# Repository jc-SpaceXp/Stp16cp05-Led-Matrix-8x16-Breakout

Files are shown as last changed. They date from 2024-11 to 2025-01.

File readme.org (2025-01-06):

* STP16CP05 LED Matrix 8x16 Breakout (0805 Metric)
Note: All components have the correct name/part-number however the description and datasheet will be incorrect (if names were changed)
** Schematic
[[file:stp16cp05_led_matrix_8x16_breakout/schematic_v04.pdf]]
** BOM
[[file:stp16cp05_led_matrix_8x16_breakout/stp16cp05_led_matrix_8x16_breakout_m0805_bom.csv]]
** 3D PCB Models
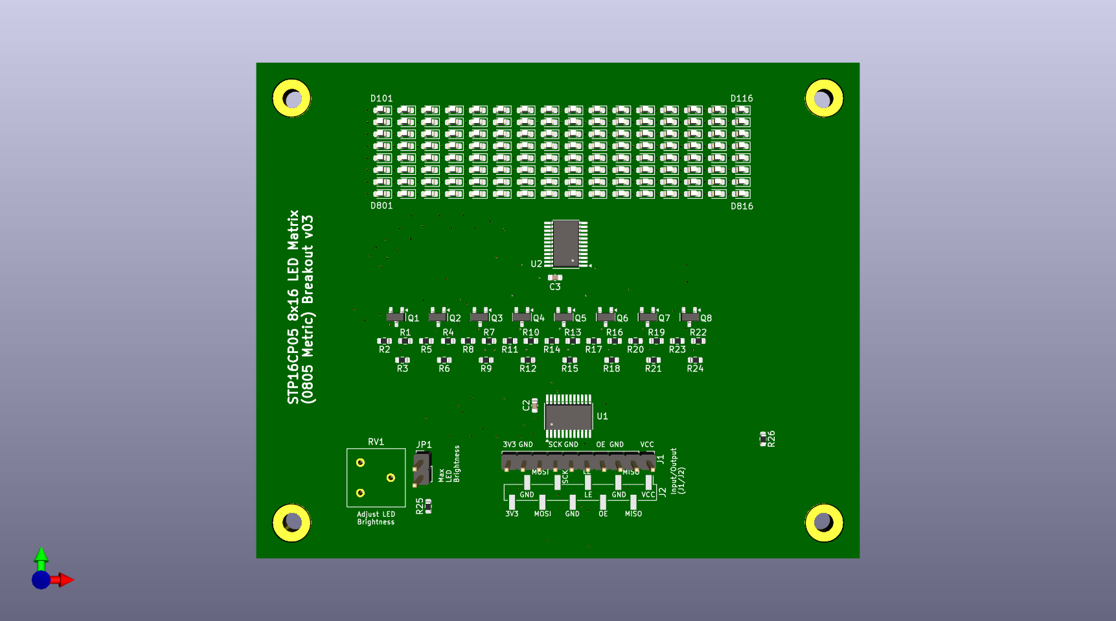
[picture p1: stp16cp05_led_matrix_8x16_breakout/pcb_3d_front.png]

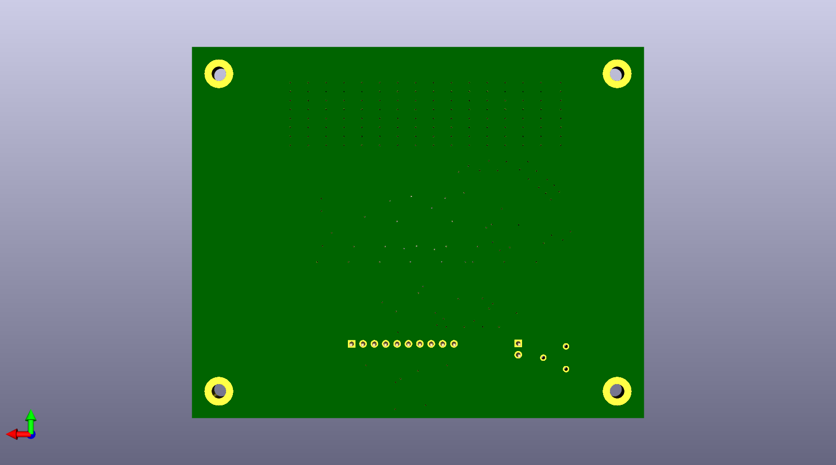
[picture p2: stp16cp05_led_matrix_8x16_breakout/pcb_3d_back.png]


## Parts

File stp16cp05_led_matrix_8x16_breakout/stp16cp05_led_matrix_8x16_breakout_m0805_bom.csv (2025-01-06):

Manufacturer Part No | Reference | Value | Qty | Footprint
C0603C104J3RACTU | C2,C3 | 100n | 2 | Capacitor_SMD:C_0603_1608Metric
LTST-C171KRKT | D101-D116,D201-D216,D301-D316,D401-D416,D501-D516,D601-D616,D701-D716,D801-D816 | LTST-C171KRKT | 128 | LED_SMD:LED_0603_1608Metric_Pad1.05x0.95mm_HandSolder
77311-101-10LF | J1 | (Input/Output) LED Matrix 2.54mm Female | 1 | Connector_PinHeader_2.54mm:PinHeader_1x10_P2.54mm_Vertical
AKSCT/G BLACK | JP1 | Short RV1 (Open) | 1 | Connector_PinHeader_2.54mm:PinHeader_1x02_P2.54mm_Vertical
DMP3125L-7 | Q1,Q2,Q3,Q4,Q5,Q6,Q7,Q8 | DMP3125L-7 | 8 | Package_TO_SOT_SMD:SOT-23
RT0603FRE075K1L | R1,R4,R7,R10,R13,R16,R19,R22 | 5K1 | 8 | Resistor_SMD:R_0603_1608Metric
RT0603DRE071KL | R2,R5,R8,R11,R14,R17,R20,R23,R25,R26 | 1K | 10 | Resistor_SMD:R_0603_1608Metric
RT0603FRE0710RL | R3,R6,R9,R12,R15,R18,R21,R24 | 10R | 8 | Resistor_SMD:R_0603_1608Metric
3386F-1-222LF | RV1 | 2K2 | 1 | Potentiometer_THT:Potentiometer_Bourns_3386F_Vertical
STP16CP05XTTR | U1,U2 | STP16CP05XT | 2 | Package_SO:HTSSOP-24-1EP_4.4x7.8mm_P0.65mm_EP3.2x5mm

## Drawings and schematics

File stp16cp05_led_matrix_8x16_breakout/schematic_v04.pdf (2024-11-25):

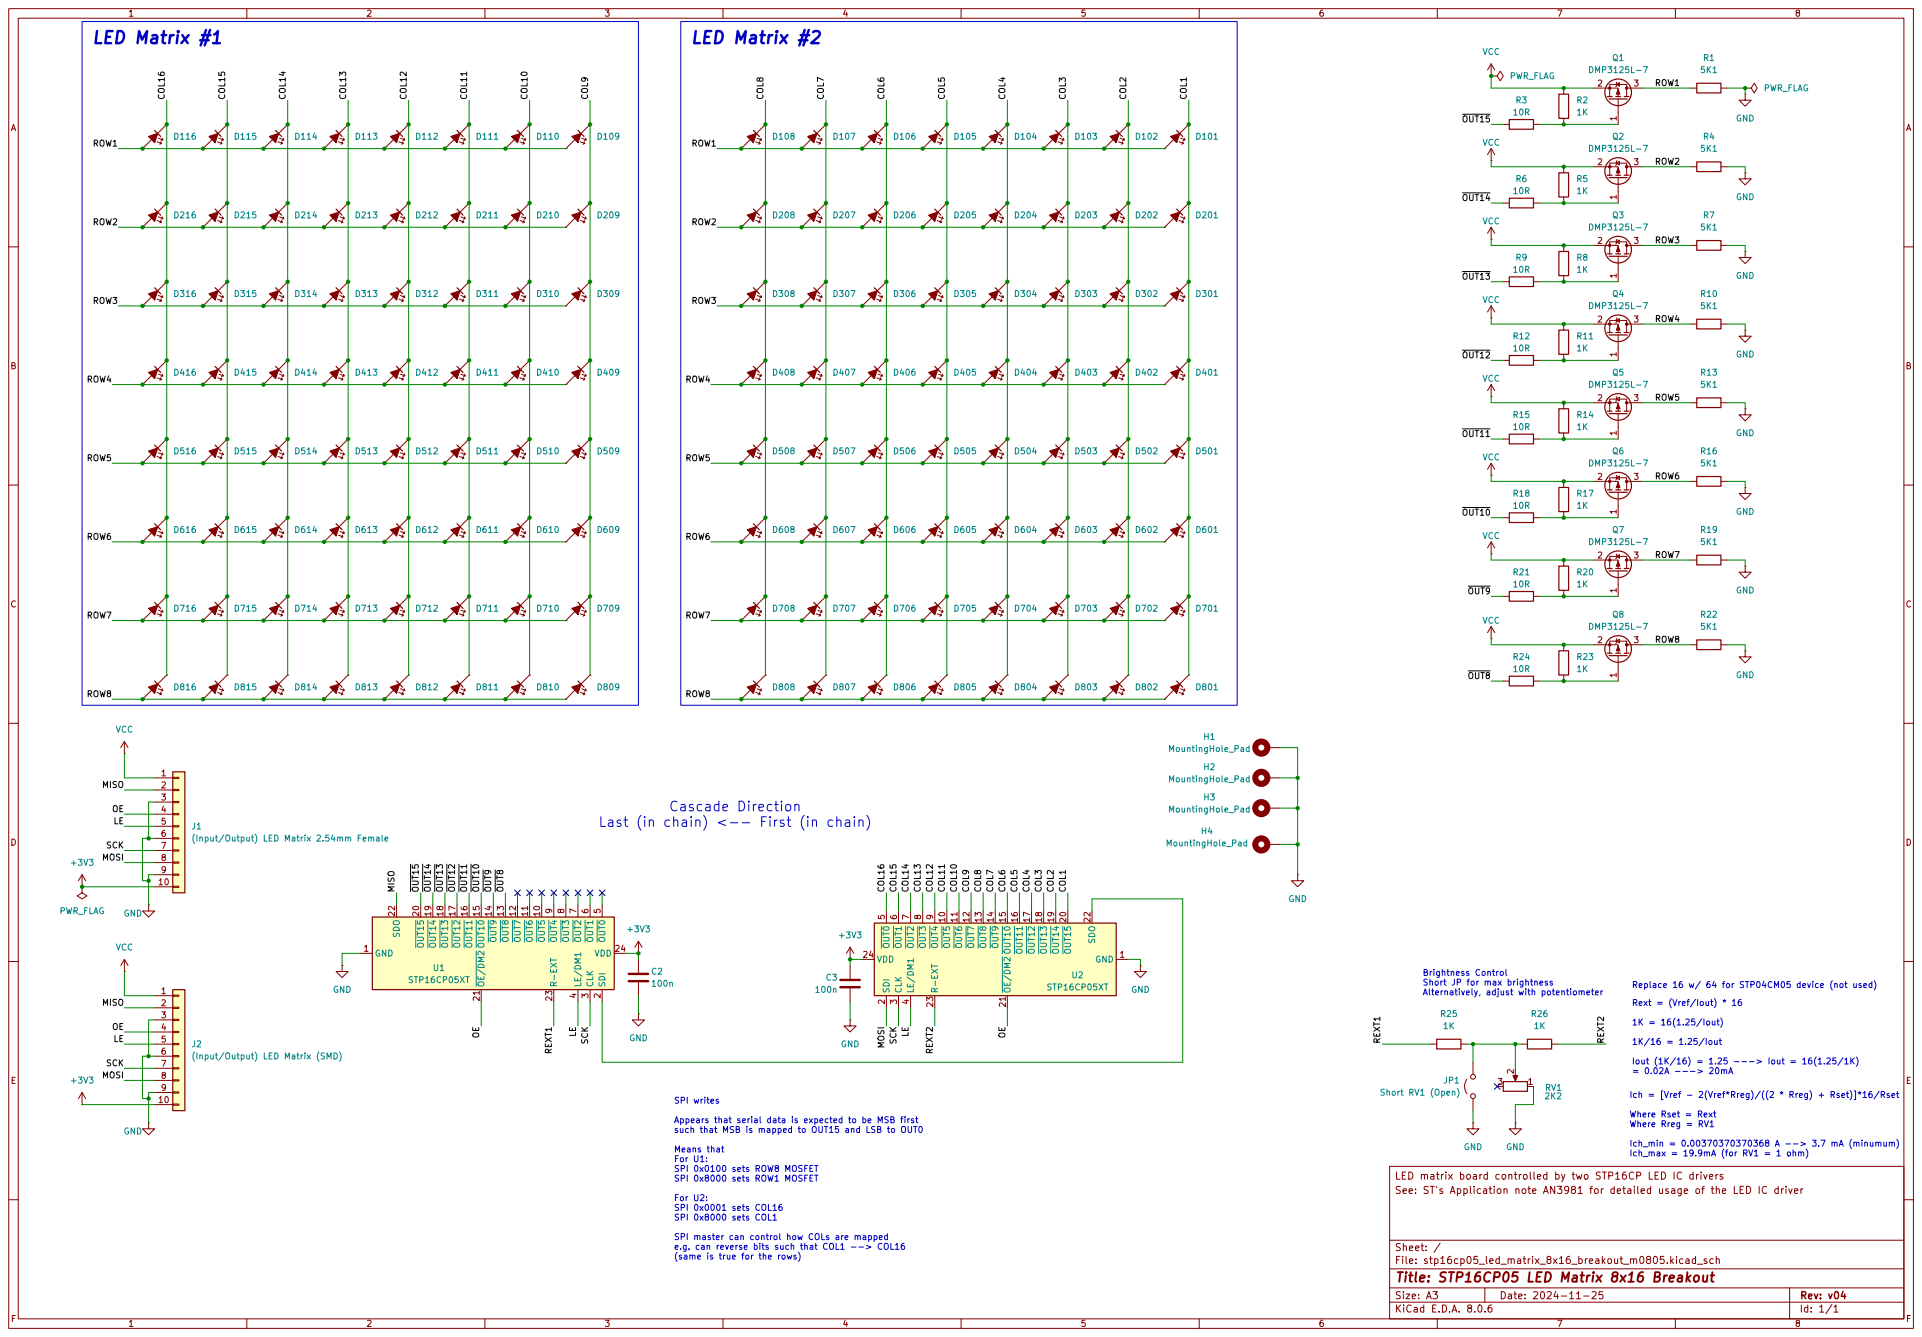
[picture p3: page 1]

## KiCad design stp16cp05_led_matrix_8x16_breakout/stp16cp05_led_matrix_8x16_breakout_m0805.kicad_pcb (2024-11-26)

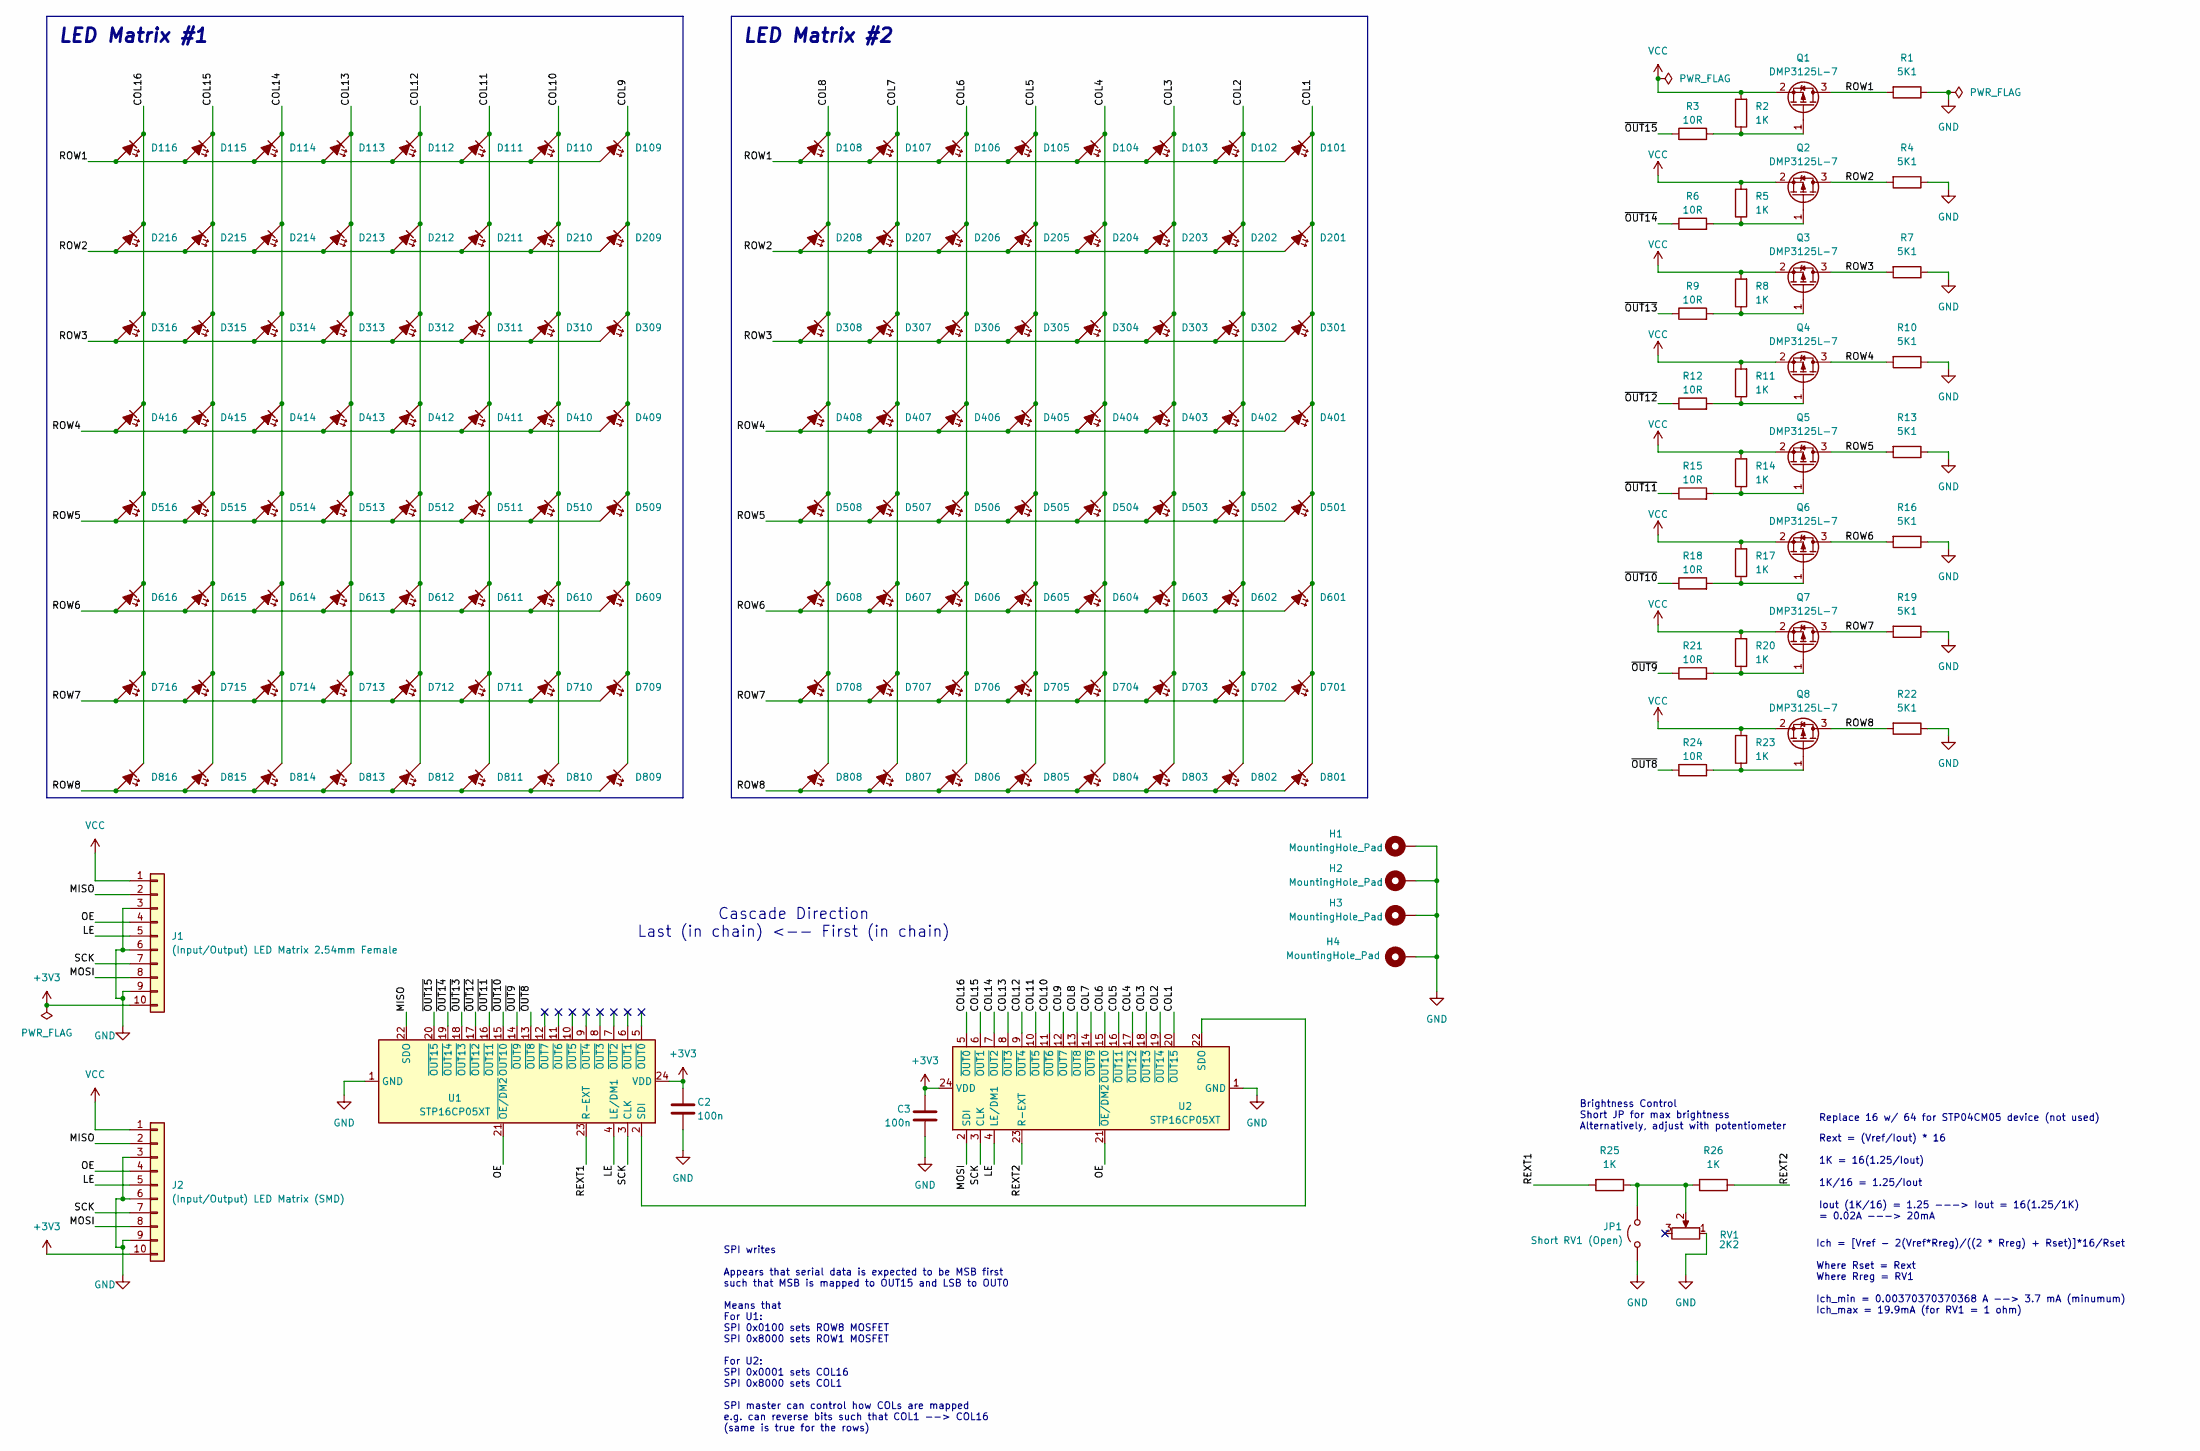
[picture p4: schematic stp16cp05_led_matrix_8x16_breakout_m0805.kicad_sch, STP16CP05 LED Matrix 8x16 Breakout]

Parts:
C2, C3: 100n; C_0603_1608Metric
D101, D102, D103, D104, D105, D106, D107, D108, D109, D110, D111, D112, D113, D114, D115, D116, D201, D202, D203, D204, D205, D206, D207, D208, D209, D210, D211, D212, D213, D214, D215, D216, D301, D302, D303, D304, D305, D306, D307, D308, D309, D310, D311, D312, D313, D314, D315, D316, D401, D402, D403, D404, D405, D406, D407, D408, D409, D410, D411, D412, D413, D414, D415, D416, D501, D502, D503, D504, D505, D506, D507, D508, D509, D510, D511, D512, D513, D514, D515, D516, D601, D602, D603, D604, D605, D606, D607, D608, D609, D610, D611, D612, D613, D614, D615, D616, D701, D702, D703, D704, D705, D706, D707, D708, D709, D710, D711, D712, D713, D714, D715, D716, D801, D802, D803, D804, D805, D806, D807, D808, D809, D810, D811, D812, D813, D814, D815, D816: LTST-C171KRKT; LED_0603_1608Metric_Pad1.05x0.95mm_HandSolder
H1, H2, H3, H4: MountingHole_Pad; MountingHole_3.2mm_M3_Pad
J1: (Input/Output) LED Matrix 2.54mm Female; PinHeader_1x10_P2.54mm_Vertical
J2: (Input/Output) LED Matrix (SMD); PinHeader_1x10_P2.54mm_Vertical_SMD_Pin1Left
JP1: Short RV1 (Open); PinHeader_1x02_P2.54mm_Vertical
Q1, Q2, Q3, Q4, Q5, Q6, Q7, Q8: DMP3125L-7; SOT-23
R1, R4, R7, R10, R13, R16, R19, R22: 5K1; R_0603_1608Metric
R2, R5, R8, R11, R14, R17, R20, R23, R25, R26: 1K; R_0603_1608Metric
R3, R6, R9, R12, R15, R18, R21, R24: 10R; R_0603_1608Metric
RV1: 2K2; Potentiometer_Bourns_3386F_Vertical
U1, U2: STP16CP05XT; HTSSOP-24-1EP_4.4x7.8mm_P0.65mm_EP3.2x5mm

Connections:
+3V3: C2.1, C3.1, J1.10, J2.10, U1.24 (VDD), U2.24 (VDD)
/COL1: D101.1 (K), D201.1 (K), D301.1 (K), D401.1 (K), D501.1 (K), D601.1 (K), D701.1 (K), D801.1 (K), U2.20 (~OUT15)
/COL2: D102.1 (K), D202.1 (K), D302.1 (K), D402.1 (K), D502.1 (K), D602.1 (K), D702.1 (K), D802.1 (K), U2.19 (~OUT14)
/COL3: D103.1 (K), D203.1 (K), D303.1 (K), D403.1 (K), D503.1 (K), D603.1 (K), D703.1 (K), D803.1 (K), U2.18 (~OUT13)
/COL4: D104.1 (K), D204.1 (K), D304.1 (K), D404.1 (K), D504.1 (K), D604.1 (K), D704.1 (K), D804.1 (K), U2.17 (~OUT12)
/COL5: D105.1 (K), D205.1 (K), D305.1 (K), D405.1 (K), D505.1 (K), D605.1 (K), D705.1 (K), D805.1 (K), U2.16 (~OUT11)
/COL6: D106.1 (K), D206.1 (K), D306.1 (K), D406.1 (K), D506.1 (K), D606.1 (K), D706.1 (K), D806.1 (K), U2.15 (~OUT10)
/COL7: D107.1 (K), D207.1 (K), D307.1 (K), D407.1 (K), D507.1 (K), D607.1 (K), D707.1 (K), D807.1 (K), U2.14 (~OUT9)
/COL8: D108.1 (K), D208.1 (K), D308.1 (K), D408.1 (K), D508.1 (K), D608.1 (K), D708.1 (K), D808.1 (K), U2.13 (~OUT8)
/COL9: D109.1 (K), D209.1 (K), D309.1 (K), D409.1 (K), D509.1 (K), D609.1 (K), D709.1 (K), D809.1 (K), U2.12 (~OUT7)
/COL10: D110.1 (K), D210.1 (K), D310.1 (K), D410.1 (K), D510.1 (K), D610.1 (K), D710.1 (K), D810.1 (K), U2.11 (~OUT6)
/COL11: D111.1 (K), D211.1 (K), D311.1 (K), D411.1 (K), D511.1 (K), D611.1 (K), D711.1 (K), D811.1 (K), U2.10 (~OUT5)
/COL12: D112.1 (K), D212.1 (K), D312.1 (K), D412.1 (K), D512.1 (K), D612.1 (K), D712.1 (K), D812.1 (K), U2.9 (~OUT4)
/COL13: D113.1 (K), D213.1 (K), D313.1 (K), D413.1 (K), D513.1 (K), D613.1 (K), D713.1 (K), D813.1 (K), U2.8 (~OUT3)
/COL14: D114.1 (K), D214.1 (K), D314.1 (K), D414.1 (K), D514.1 (K), D614.1 (K), D714.1 (K), D814.1 (K), U2.7 (~OUT2)
/COL15: D115.1 (K), D215.1 (K), D315.1 (K), D415.1 (K), D515.1 (K), D615.1 (K), D715.1 (K), D815.1 (K), U2.6 (~OUT1)
/COL16: D116.1 (K), D216.1 (K), D316.1 (K), D416.1 (K), D516.1 (K), D616.1 (K), D716.1 (K), D816.1 (K), U2.5 (~OUT0)
/LE: J1.5, J2.5, U1.4 (LE/DM1), U2.4 (LE/DM1)
/MISO: J1.2, J2.2, U1.22 (SDO)
/MOSI: J1.8, J2.8, U2.2 (SDI)
/OE: J1.4, J2.4, U1.21 (~OE/DM2), U2.21 (~OE/DM2)
/REXT1: R25.2, U1.23 (R-EXT)
/REXT2: R26.1, U2.23 (R-EXT)
/ROW1: D101.2 (A), D102.2 (A), D103.2 (A), D104.2 (A), D105.2 (A), D106.2 (A), D107.2 (A), D108.2 (A), D109.2 (A), D110.2 (A), D111.2 (A), D112.2 (A), D113.2 (A), D114.2 (A), D115.2 (A), D116.2 (A), Q1.3 (D), R1.2
/ROW2: D201.2 (A), D202.2 (A), D203.2 (A), D204.2 (A), D205.2 (A), D206.2 (A), D207.2 (A), D208.2 (A), D209.2 (A), D210.2 (A), D211.2 (A), D212.2 (A), D213.2 (A), D214.2 (A), D215.2 (A), D216.2 (A), Q2.3 (D), R4.2
/ROW3: D301.2 (A), D302.2 (A), D303.2 (A), D304.2 (A), D305.2 (A), D306.2 (A), D307.2 (A), D308.2 (A), D309.2 (A), D310.2 (A), D311.2 (A), D312.2 (A), D313.2 (A), D314.2 (A), D315.2 (A), D316.2 (A), Q3.3 (D), R7.2
/ROW4: D401.2 (A), D402.2 (A), D403.2 (A), D404.2 (A), D405.2 (A), D406.2 (A), D407.2 (A), D408.2 (A), D409.2 (A), D410.2 (A), D411.2 (A), D412.2 (A), D413.2 (A), D414.2 (A), D415.2 (A), D416.2 (A), Q4.3 (D), R10.2
/ROW5: D501.2 (A), D502.2 (A), D503.2 (A), D504.2 (A), D505.2 (A), D506.2 (A), D507.2 (A), D508.2 (A), D509.2 (A), D510.2 (A), D511.2 (A), D512.2 (A), D513.2 (A), D514.2 (A), D515.2 (A), D516.2 (A), Q5.3 (D), R13.2
/ROW6: D601.2 (A), D602.2 (A), D603.2 (A), D604.2 (A), D605.2 (A), D606.2 (A), D607.2 (A), D608.2 (A), D609.2 (A), D610.2 (A), D611.2 (A), D612.2 (A), D613.2 (A), D614.2 (A), D615.2 (A), D616.2 (A), Q6.3 (D), R16.2
/ROW7: D701.2 (A), D702.2 (A), D703.2 (A), D704.2 (A), D705.2 (A), D706.2 (A), D707.2 (A), D708.2 (A), D709.2 (A), D710.2 (A), D711.2 (A), D712.2 (A), D713.2 (A), D714.2 (A), D715.2 (A), D716.2 (A), Q7.3 (D), R19.2
/ROW8: D801.2 (A), D802.2 (A), D803.2 (A), D804.2 (A), D805.2 (A), D806.2 (A), D807.2 (A), D808.2 (A), D809.2 (A), D810.2 (A), D811.2 (A), D812.2 (A), D813.2 (A), D814.2 (A), D815.2 (A), D816.2 (A), Q8.3 (D), R22.2
/SCK: J1.7, J2.7, U1.3 (CLK), U2.3 (CLK)
/~OUT8: R24.1, U1.13 (~OUT8)
/~OUT9: R21.1, U1.14 (~OUT9)
/~OUT10: R18.1, U1.15 (~OUT10)
/~OUT11: R15.1, U1.16 (~OUT11)
/~OUT12: R12.1, U1.17 (~OUT12)
/~OUT13: R9.1, U1.18 (~OUT13)
/~OUT14: R6.1, U1.19 (~OUT14)
/~OUT15: R3.1, U1.20 (~OUT15)
GND: C2.2, C3.2, H1.1, H2.1, H3.1, H4.1, J1.3, J1.6, J1.9, J2.3, J2.6, J2.9, JP1.1 (A), R1.1, R4.1, R7.1, R10.1, R13.1, R16.1, R19.1, R22.1, RV1.1, U1.1 (GND), U1.25 (GND), U2.1 (GND), U2.25 (GND)
unnamed: JP1.2 (B), R25.1, R26.2, RV1.2
unnamed: Q1.1 (G), R2.1, R3.2
unnamed: Q2.1 (G), R5.1, R6.2
unnamed: Q3.1 (G), R8.1, R9.2
unnamed: Q4.1 (G), R11.1, R12.2
unnamed: Q5.1 (G), R14.1, R15.2
unnamed: Q6.1 (G), R17.1, R18.2
unnamed: Q7.1 (G), R20.1, R21.2
unnamed: Q8.1 (G), R23.1, R24.2
unnamed: U1.2 (SDI), U2.22 (SDO)
VCC: J1.1, J2.1, Q1.2 (S), Q2.2 (S), Q3.2 (S), Q4.2 (S), Q5.2 (S), Q6.2 (S), Q7.2 (S), Q8.2 (S), R2.2, R5.2, R8.2, R11.2, R14.2, R17.2, R20.2, R23.2

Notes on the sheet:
LED Matrix #1
LED Matrix #2
Cascade Direction Last (in chain) <-- First (in chain)
Rext = (Vref/Iout) * 16 1K = 16(1.25/Iout) 1K/16 = 1.25/Iout Iout (1K/16) = 1.25 ---> Iout = 16(1.25/1K) = 0.02A ---> 20mA
Ich = [Vref - 2(Vref*Rreg)/((2 * Rreg) + Rset)]*16/Rset Where Rset = Rext Where Rreg = RV1 Ich_min = 0.00370370370368 A --> 3.7 mA (minumum) Ich_max = 19.9mA (for RV1 = 1 ohm)
Replace 16 w/ 64 for STP04CM05 device (not used)
SPI writes Appears that serial data is expected to be MSB first such that MSB is mapped to OUT15 and LSB to OUT0 Means that For U1: SPI 0x0100 sets ROW8 MOSFET SPI 0x8000 sets ROW1 MOSFET For U2: SPI 0x0001 sets COL16 SPI 0x8000 sets COL1 SPI master can control how COLs are mapped e.g. can reverse 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
Brightness Control Short JP for max brightness Alternatively, adjust with potentiometer

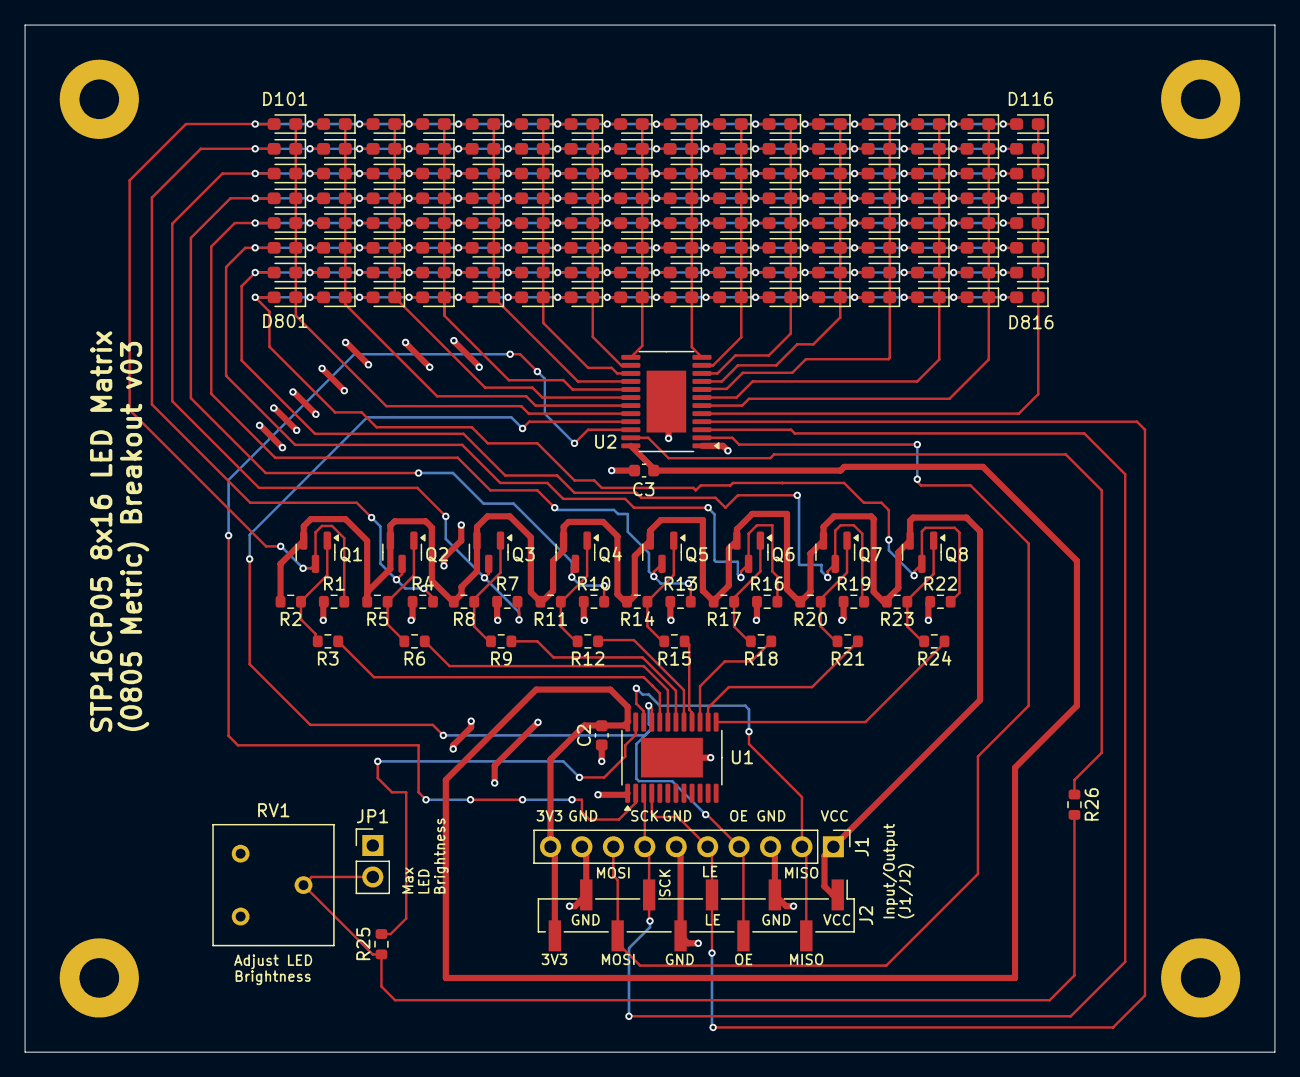
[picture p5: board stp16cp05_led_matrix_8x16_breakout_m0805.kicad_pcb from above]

Board: 2 copper layers, 101.0 x 83.0 mm, 174 parts (0 on the bottom side), 52 nets.

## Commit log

2024-11-18 Add kicad project files
    - Initial PCB version has D101 as the top right LED
    [stp16cp05_led_matrix_8x16_breakout_m0805.kicad_pcb, stp16cp05_led_matrix_8x16_breakout_m0805.kicad_sch]
2024-11-18 Updated pcb
    - D101 is now the most bottom left, going x01 to x116 from left to right
    and 1xx to 8xx going from bottom to top
    [stp16cp05_led_matrix_8x16_breakout_m0805.kicad_pcb]
2024-11-18 Add schematic (pdf)
2024-11-18 Update schematic
    - Use 3V3 net name over 3.3V (decimal point is hard to see in PDF)
    [stp16cp05_led_matrix_8x16_breakout_m0805.kicad_sch]
2024-11-18 Update pcb (shcematic changes)
    - Pull in changes to schematic
    [stp16cp05_led_matrix_8x16_breakout_m0805.kicad_pcb]
2024-11-25 Update 3d models in pcb
    [stp16cp05_led_matrix_8x16_breakout_m0805.kicad_pcb]
2024-11-25 Add gerber options
    [stp16cp05_led_matrix_8x16_breakout_m0805.kicad_pcb]
2024-11-25 Add gerber files
    - Settings matching OSH Park fab house
    [stp16cp05_led_matrix_8x16_breakout_m0805-B_Cu.gbr, stp16cp05_led_matrix_8x16_breakout_m0805-B_Mask.gbr, stp16cp05_led_matrix_8x16_breakout_m0805-B_Paste.gbr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]
2024-11-25 Remove jpegs
    - PNGs load better, silkscreen is much clearer
2024-11-25 Add gerber plots settings to kicad project file
2024-11-25 Add comments for schematic
    - Added helpful comments for expected SPI writes and how this effects
    which ROW/COL turns on
    - Ideally LED ROWs should be inverted on PCB to minimise signals
    crossing between layers
    [stp16cp05_led_matrix_8x16_breakout_m0805.kicad_sch]
2024-11-26 Update pcb (flip led rows)
    - Flipped LED rows to stop the crossing tracks between layers
    - Updated gerbers and images too
    [stp16cp05_led_matrix_8x16_breakout_m0805-B_Cu.gbr, stp16cp05_led_matrix_8x16_breakout_m0805-B_Mask.gbr, stp16cp05_led_matrix_8x16_breakout_m0805-B_Paste.gbr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]
2024-11-26 Update kicad file
2024-11-26 Add pcb revision number and text (to front silkscreen)
    [stp16cp05_led_matrix_8x16_breakout_m0805.kicad_pcb]
2024-11-26 Update 3d render and gerbers
    [stp16cp05_led_matrix_8x16_breakout_m0805-F_Cu.gbr, stp16cp05_led_matrix_8x16_breakout_m0805-F_Silkscreen.gbr, stp16cp05_led_matrix_8x16_breakout_m0805-job.gbrj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]
2025-01-06 Add manufacturer part numbers to schematic symbols
    [stp16cp05_led_matrix_8x16_breakout_m0805.kicad_sch]
2025-01-06 Add setting for BOM output file
    - Tweaked other settings to hide DNP fields and datasheet fields too
    from symbol lists
2025-01-06 Add bom csv file
    [stp16cp05_led_matrix_8x16_breakout_m0805_bom.csv]
2025-01-06 Update readme to include bom
2025-01-06 Exclude smd footprint from bom
    - Just some SMD pads which don't require a part
    [stp16cp05_led_matrix_8x16_breakout_m0805.kicad_sch]
